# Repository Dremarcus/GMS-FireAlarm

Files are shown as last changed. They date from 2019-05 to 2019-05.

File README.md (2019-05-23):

# GSM-FireAlarm
Požární hlásič s odesíláním zpráv přes GSM
Použitý modul Arduino nano,NiceRF, SIM800L a Digispark
Funkce:
Čidlo kouře pošle přes NiceRF a Digispark kód ->
NiceRF příjme zprávu, kterou předá Arduino NANO ->
NANO vyhodnotí zprávu a počká až bude souhlasit počet přijatých zpráv ->
Po dosažení počtu, zapne LED a spustí sirénu ->
Následně osloví SIM800L aby poslalo SMS na tel.čísla a poté zavolal na tel.čísla ->
Poté se restartuje celé zařízení.

Dlouho jsem se pokoušel zprovoznit vícenásobné poslání SMS a Volání.
Nakonec používám před každým odesláním SMS aktivaci TEXT módu a funguje to i na xy čísel pod sebou
S voláním jsem nepochopil, proč nelze opakovat volání...
Až po nějaké době(cca2 měsíce sem tam odpoledne) jsem zkusil restartovat modul SIM800L a ejhle, ono to jede...
Takže po zavolání - reset - a před dalším voláním - start -

Použil jsem NANO ale má to nevýhodu s pamětí.
Omezení pro proměnné je jen 1kB, nevím jesti větší modul má více...
Tudíž je omezení na 2 telefonní čísla
Chtěl jsem dát 7 ale 190 bytů se mu zdá málo

Celkový program zabírá:
Projekt zabírá 9220 bytů (64%)  úložného místa pro program. Maximum je 14336 bytů.
Globální proměnné zabírají 764 bytů (74%)  dynamické paměti, 260 bytů zůstává pro lokální proměnné. Maximum je 1024 bytů.

Použitá knihovna GSMSim.h je naprosto perfektní!!! Díky erdemarslan

Přikládám Eagle DPS celého projektu
DPS je vyrobena pro krabici DLS routeru Zyxel P-660HN-T3A
Ve schématu je jen chybička- R6 je výstup na sirénu (bez odporu)

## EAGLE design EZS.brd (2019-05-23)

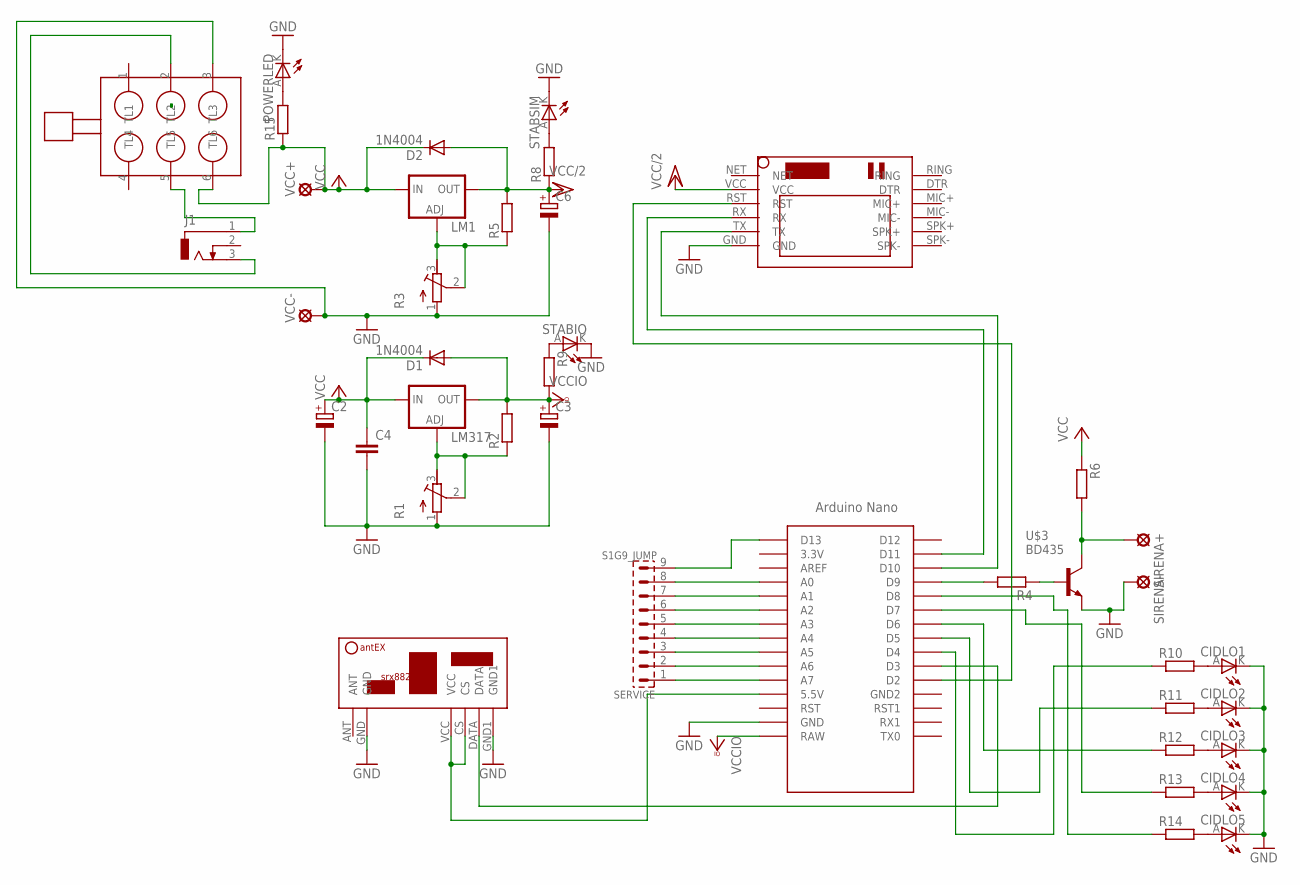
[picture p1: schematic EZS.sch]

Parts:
C2, C3, C6: CPOL-EUE3.5-8; E3,5-8
C4: C-EU102-064X133; C102-064X133
CIDLO1, CIDLO2, CIDLO3, CIDLO4, CIDLO5: LEDLED3MM; LED3MM
D1, D2: 1N4004; DO41-10
J1: DCJ0303
LM1, LM317: LM317TS; 317TS
POWERLED: LEDLED3MM; LED3MM
R1, R3: R-TRIMM64Y; RTRIM64Y
R2, R4, R5, R6, R8, R9, R10, R11, R12, R13, R14, R15: R-EU_0207/10; 0207/10
SERVICE: S1G9_JUMP; S1G9_JUM
SIM800L: SIM800LMODULE
SIRENA+: LSP11
SIRENA-: LSP11
STABIO: LEDLED3MM; LED3MM
STABSIM: LEDLED3MM; LED3MM
U$1: NANO
U$2: RSX882; SRX882
U$3: BD435
U$4: TLACITKO
VCC+: LSP11
VCC-: LSP11

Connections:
GND: C2.-, C3.-, C4.2, C6.-, CIDLO1.K (C), CIDLO2.K (C), CIDLO3.K (C), CIDLO4.K (C), CIDLO5.K (C), POWERLED.K (C), R1.1 (A), R3.1 (A), SIM800L.GND, SIRENA-.MP, STABIO.K (C), STABSIM.K (C), U$1.GND, U$2.GND, U$2.GND1, U$3.E, U$4.3 (TL3), VCC-.MP
unnamed: U$1.D3, U$2.DATA
unnamed: LM317.1 (ADJ), R1.2 (S), R1.3 (E), R2.1
unnamed: U$1.5V (5.5V), U$2.CS, U$2.VCC
unnamed: R8.2, STABSIM.A
unnamed: SIM800L.RX, U$1.D11
unnamed: LM1.1 (ADJ), R3.2 (S), R3.3 (E), R5.1
unnamed: SIM800L.TX, U$1.D10
unnamed: R4.2, U$1.D9
unnamed: R4.1, U$3.B
unnamed: R6.2, SIRENA+.MP, U$3.C
unnamed: J1.1, U$4.5 (TL5)
unnamed: J1.3, U$4.2 (TL2)
unnamed: POWERLED.A, R15.2
unnamed: SIM800L.RST, U$1.D2
unnamed: CIDLO1.A, R10.2
unnamed: CIDLO2.A, R11.2
unnamed: CIDLO3.A, R12.2
unnamed: CIDLO4.A, R13.2
unnamed: CIDLO5.A, R14.2
unnamed: R13.1, U$1.D7
unnamed: R10.1, U$1.D4
unnamed: R12.1, U$1.D6
unnamed: SERVICE.1, U$1.A7
unnamed: R9.1, STABIO.A
unnamed: R11.1, U$1.D5
unnamed: R14.1, U$1.D8
unnamed: SERVICE.2, U$1.A6
unnamed: SERVICE.3, U$1.A5
unnamed: SERVICE.4, U$1.A4
unnamed: SERVICE.5, U$1.A3
unnamed: SERVICE.6, U$1.A2
unnamed: SERVICE.7, U$1.A1
unnamed: SERVICE.8, U$1.A0
unnamed: SERVICE.9, U$1.D13
VCC: C2.+, C4.1, D1.C, D2.C, LM1.3 (IN), LM317.3 (IN), R6.1, R15.1, U$4.6 (TL6), VCC+.MP
VCC/2: C6.+, D2.A, LM1.2 (OUT), R5.2, R8.1, SIM800L.VCC
VCCIO: C3.+, D1.A, LM317.2 (OUT), R2.2, R9.2, U$1.RAW

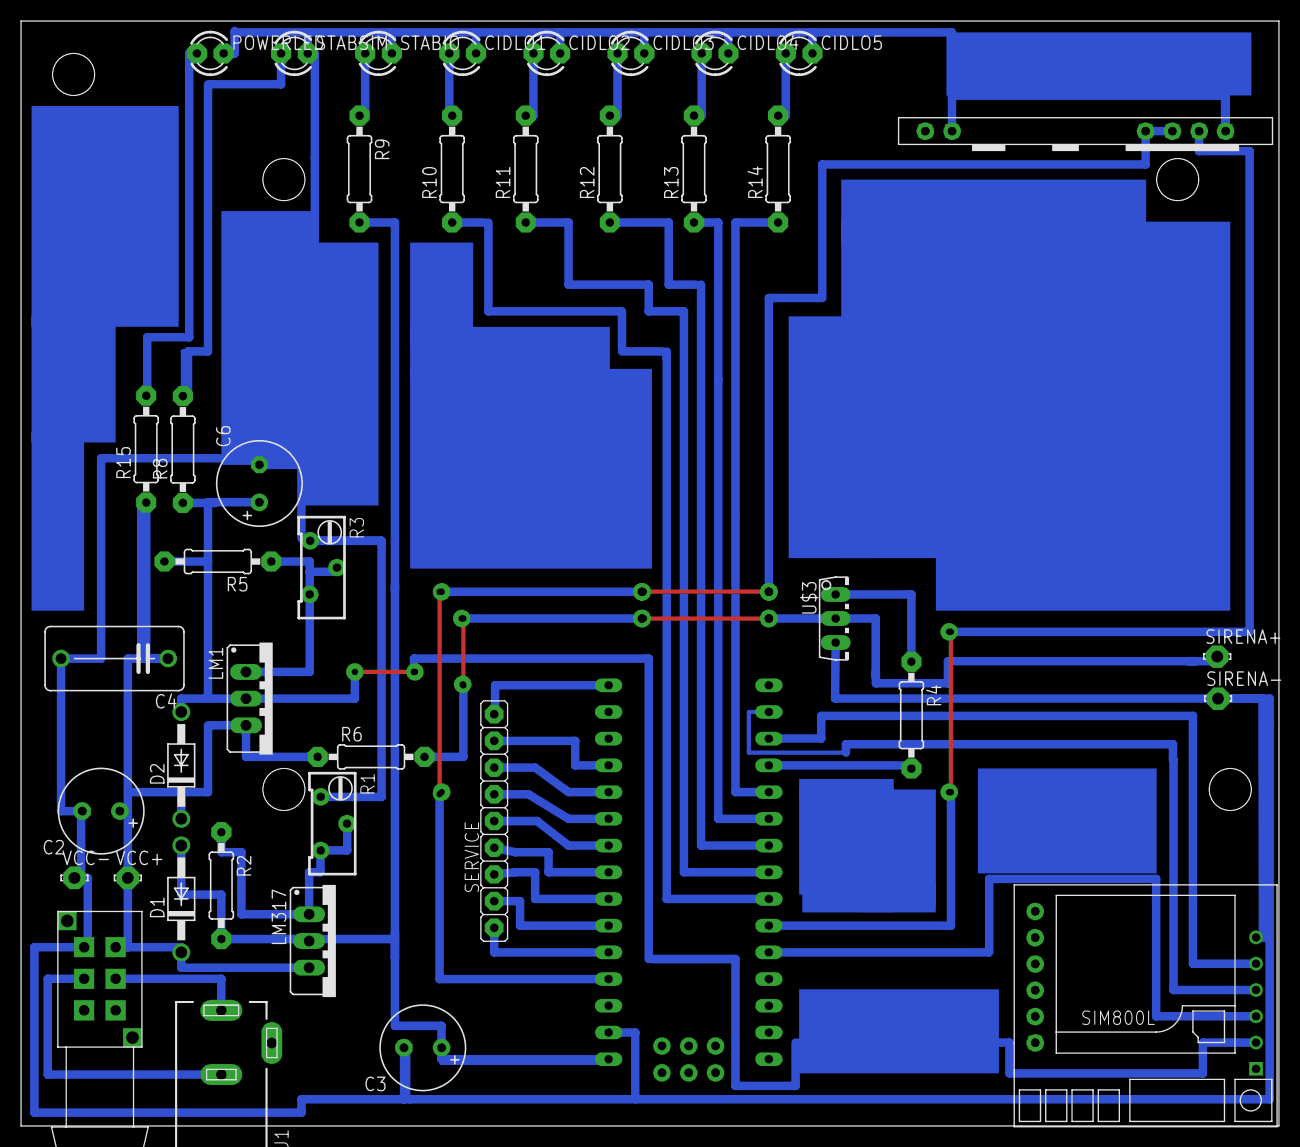
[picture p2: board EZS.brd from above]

Board: 2 copper layers, 119.6 x 105.1 mm, 41 parts (0 on the bottom side), 38 nets.

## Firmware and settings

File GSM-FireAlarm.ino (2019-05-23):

// GSM požární hlásič
// Arduino nano ATmega168
// D2-RST(sim800l800L); D3-DATA(SRX882); D4-LED1; D5-LED2; D6-LED3; D7-LED4; D8-LED5; D9-Buzzer out; D10-TX(SIM800L); D11-RX(SIM800L); D13+A0-->A7-Volné piny;
// NiceRF 433MHz Přijímač SRX887

// připojení potřebné knihovny
#include <RCSwitch.h>
#include <GSMSim.h>

#define RX 10
#define TX 11
#define RESET 2
#define BAUD 9600                                

//definice připojení pinu k arduinu
RCSwitch prijimac = RCSwitch();                             //Vytvoření objektu přijímače z knihovny
GSMSim gsm(RX, TX, RESET);

char* number1 = "+420xxxxxxxxx";
char* number2 = "+420xxxxxxxxx";

char* message = "Pozar v dome!!!";

long ZPRAVA1 = 1511;                                         //Kód přijetí z vysílače č.1
long ZPRAVA2 = 1512;                                         //Kód přijetí z vysílače č.2
long ZPRAVA3 = 1513;                                         //Kód přijetí z vysílače č.3
long ZPRAVA4 = 1514;                                         //Kód přijetí z vysílače č.4
long ZPRAVA5 = 1515;                                         //Kód přijetí z vysílače č.5

//proměnné pro výstupy z arduina
int piezo = 9;                                              //výstupní repro z pinu č.9
int Led1 = 4;                                               //Led čidlo 1
int Led2 = 5;                                               //Led čidlo 2
int Led3 = 6;                                               //Led čidlo 3
int Led4 = 7;                                               //Led čidlo 4
int Led5 = 8;                                               //Led čidlo 5

//čítač počtu příchozích zpráv
int citacCidlo1 = 0;
int citacCidlo2 = 0;
int citacCidlo3 = 0;
int citacCidlo4 = 0;
int citacCidlo5 = 0;

//limit příchodů zpráv 
const int LIMIT_CITAC = 3;

void setup() {
  pinMode(piezo, OUTPUT);                                   //--->Nastavení jako výstupní zařízení
  pinMode(Led1, OUTPUT);
  pinMode(Led2, OUTPUT);
  pinMode(Led3, OUTPUT);
  pinMode(Led4, OUTPUT);
  pinMode(Led5, OUTPUT);
  digitalWrite(piezo, LOW);                                 // Piezo jako výstup, na začátku 0 kvůli tichosti
  Serial.begin(9600);                                       // Zahájení komunikace po sériové lince
  delay(1000); 
  gsm.start();                                              //Zahájení komunikace mezi arduinem a SIM800L
  delay(1000); 
  Serial.println("Program nahrán");
  delay(1000);                                              //Prodleva spuštění
  prijimac.enableReceive(1);                                // nastavení přijacího pinu RFmodulu na interrupt pin 1 = pin D3 pro Nano
  delay(1000); 
    digitalWrite(Led1, HIGH);                               //--->Start kontrolek LED 1-->5
  delay(500);
  digitalWrite(Led1, LOW);
    digitalWrite(Led2, HIGH);
  delay(500);
  digitalWrite(Led2, LOW);
    digitalWrite(Led3, HIGH);
  delay(500);
  digitalWrite(Led3, LOW);
   digitalWrite(Led4, HIGH);
  delay(500);
  digitalWrite(Led4, LOW);
    digitalWrite(Led5, HIGH);
  delay(500);
  digitalWrite(Led5, LOW);
  }
  
void(* resetFunc) (void) = 0;                       //Deklarace funkce reset @ address 0

void loop(){
   if (prijimac.available())                        // detekce přichozí komunikace
   {
     Serial.println("dostal jsem zpravu ");
     zpracujZpravu();
   }
   else                                              // v případě úspěšné přijaté zprávy vypíšeme všechny údaje
   {
     //Serial.println("Ted cekam");
   }
   prijimac.resetAvailable();                        // reset modulu pro přijetí nových zpráv
}

void zpracujZpravu(){
  //pripad - Cidlo1
  if (prijimac.getReceivedValue() == ZPRAVA1)         // když bude souhlasit zpráva
  {
    citacCidlo1 = citacCidlo1 + 1;                    // počítání přijatých zpráv
    if (citacCidlo1 >= LIMIT_CITAC)                   // až bude počet přijatých větší nebo rovno
    { 
      digitalWrite(Led1, HIGH);                       // Led1 zapni
      digitalWrite(piezo, HIGH);                      // Spuštění sireny na pinu č.9
      setPDU();                                       // TEXT mode
      sms1();                                         // pokračuj na SMS
      setPDU();                                       // TEXT mode
      sms2();                                         // pokračuj na SMS
      call1();                                        // pokračuj na volání
      call2();                                        // pokračuj na volání
      resetFunc();                                    // Reset zařízení
    }
  }
  //pripad - Cidlo2
  if (prijimac.getReceivedValue() == ZPRAVA2)
  {
    citacCidlo2 = citacCidlo2 + 1;
    if (citacCidlo2 >= LIMIT_CITAC)
    { 
      digitalWrite(Led2, HIGH);                       // Led2 zapni
      digitalWrite(piezo, HIGH);                      // Spuštění sireny na pinu č.9
      setPDU();                                       // TEXT mode
      sms1();                                         // pokračuj na SMS
      setPDU();                                       // TEXT mode
      sms2();                                         // pokračuj na SMS
      call1();                                        // pokračuj na volání
      call2();                                        // pokračuj na volání
      resetFunc();                                    // Reset zařízení
    }
  }
  //pripad - Cidlo3
  if (prijimac.getReceivedValue() == ZPRAVA3)
  {
    citacCidlo3 = citacCidlo3 + 1;
    if (citacCidlo3 >= LIMIT_CITAC)
    { 
      digitalWrite(Led3, HIGH);                       // Led3 zapni
      digitalWrite(piezo, HIGH);                      // Spuštění sireny na pinu č.9
      setPDU();                                       // TEXT mode
      sms1();                                         // pokračuj na SMS
      setPDU();                                       // TEXT mode
      sms2();                                         // pokračuj na SMS
      call1();                                        // pokračuj na volání
      call2();                                        // pokračuj na volání
      resetFunc();                                    // Reset zařízení
    }
  }
  //pripad - Cidlo4
  if (prijimac.getReceivedValue() == ZPRAVA4)
  {
    citacCidlo4 = citacCidlo4 + 1;
    if (citacCidlo4 >= LIMIT_CITAC)
    { 
      digitalWrite(Led4, HIGH);                       // Led4 zapni
      digitalWrite(piezo, HIGH);                      // Spuštění sireny na pinu č.9
      setPDU();                                       // TEXT mode
      sms1();                                         // pokračuj na SMS
      setPDU();                                       // TEXT mode
      sms2();                                         // pokračuj na SMS
      call1();                                        // pokračuj na volání
      call2();                                        // pokračuj na volání
      resetFunc();                                    // Reset zařízení
    }
  }
  //pripad - Cidlo5
  if (prijimac.getReceivedValue() == ZPRAVA5)
  {
    citacCidlo5 = citacCidlo5 + 1;
    if (citacCidlo5 >= LIMIT_CITAC)
    { 
      digitalWrite(Led5, HIGH);                       // Led5 zapni
      digitalWrite(piezo, HIGH);                      // Spuštění sireny na pinu č.9
      setPDU();                                       // TEXT mode
      sms1();                                         // pokračuj na SMS
      setPDU();                                       // TEXT mode
      sms2();                                         // pokračuj na SMS
      call1();                                        // pokračuj na volání
      call2();                                        // pokračuj na volání
      resetFunc();                                    // Reset zařízení
    }
  }
}
void sms1(){
  //funkce poslání SMS
  Serial.println("Odesilam sms...");
  Serial.println(gsm.smsSend(number1, message)); // if success it returns true (1) else false (0)
  delay(10000);
  } 
void sms2(){
  //funkce poslání SMS
  Serial.println("Odesilam sms...");
  Serial.println(gsm.smsSend(number2, message)); // if success it returns true (1) else false (0)
  delay(10000);
  }
 
void call1(){
  //funkce volání
  gsm.start();
  delay(2000);
  Serial.println("Volam...");
  Serial.println(gsm.call(number1));
  delay(45000);
  Serial.println("Zavesuji");
  gsm.callHangoff();
  delay(2000);
  gsm.reset();
  delay(13000);
  }
void call2(){
  //funkce volání
  gsm.start();
  Serial.println("Volam...");
  Serial.println(gsm.call(number2));
  delay(45000);
  Serial.println("Zavesuji");
  gsm.callHangoff();
  delay(2000);
  }

void vypisZpravu(){
  Serial.println("Prijata zprava: ");
  Serial.println(prijimac.getReceivedValue());
  }
void setPDU(){
  delay(1000);
  Serial.println("Prepinam na TEXT.");
  gsm.smsTextMode(true); // TEXT or PDU mode. TEXT is readable :)
  delay(1000);
  }

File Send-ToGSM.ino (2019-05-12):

// Vysílač k GSM požárnímu hlásiči
// ATTINY85 Digispark (Default, 16,5MHz)
// D0-DATA(STX882); D1-->D5-Volné piny
// NiceRF 433MHz Vysílač STX882
// Celkem 5 vysílačů:
// 1.vysílač hodnota: 1511
// 2.vysílač hodnota: 1512
// 3.vysílač hodnota: 1513
// 4.vysílač hodnota: 1514
// 5.vysílač hodnota: 1515

// připojení potřebné knihovny
#include <RCSwitch.h>

RCSwitch vysilac = RCSwitch();                              // Vytvoření objektu vysílače z knihovny
int TXDATA = 0;                                             // Definice pinu DATA připojeného k ATTINY85
int LED = 1;                                                // Definice indikační LED na ATTINY85 - Buildin

const int POCET_ODESILANI = 10;

void setup() {
  vysilac.enableTransmit(TXDATA);                           // Zahájení vysílání na pinu D0
  vysilac.setProtocol(1);                                   // Možnost změnit protokol na č.2
//vysilac.setRepeatTransmit(10);                            // Volba počtu opakování zaslání zprávy
  pinMode(LED, OUTPUT);                                     // Nastavení LED jako výstup

  for (int i = 1; i <= POCET_ODESILANI; i++)
  {
    posliZpravu();
  }
}

void loop() {
}

void posliZpravu()
{
  vysilac.send(1515, 24);                                   // Poslání čísla
  digitalWrite(LED,HIGH);                                   // Zapnutí LED
  delay(1000);                                              // Časová prodleva
  digitalWrite(LED,LOW);                                    // Vypnutí LED
  delay(2000);                                              // Prodleva mezi smyčkou (LOOP)
}

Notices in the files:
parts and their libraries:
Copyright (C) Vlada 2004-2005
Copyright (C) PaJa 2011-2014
